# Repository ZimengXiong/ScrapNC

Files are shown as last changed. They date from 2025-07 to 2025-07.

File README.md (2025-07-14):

# ScrapNC

Low Cost, 3D Printed, minimally performant, scalable CNC router for low demanding workloads like plastics, wood, cardboard, and plotting made from common 3D Printer components; specifically upcycled from the [VzBot-330](https://github.com/VzBoT3D/VzBoT-Vz330) and the [Ender-3](https://github.com/Creality3DPrinting/Ender-3).

View the 3D Model [here](https://cad.onshape.com/documents/cc222f90ad821ffcf8e9cb61/w/239149645e138bc8923f3c63/e/6d84ac4b2727319282d79423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) in the browser.

GCode Generated with [Carbide Create](https://carbide3d.com/carbidecreate/), with custom [post-processor](CarbideCreatePostProcessor/scrapnc.post)

Runs standard [Klipper](https://github.com/Klipper3d/klipper) with [custom config](KlipperConfig)

View the models here: https://www.printables.com/model/1347866-scrapnc-low-cost-cnc-router-from-3d-printer-compon/files
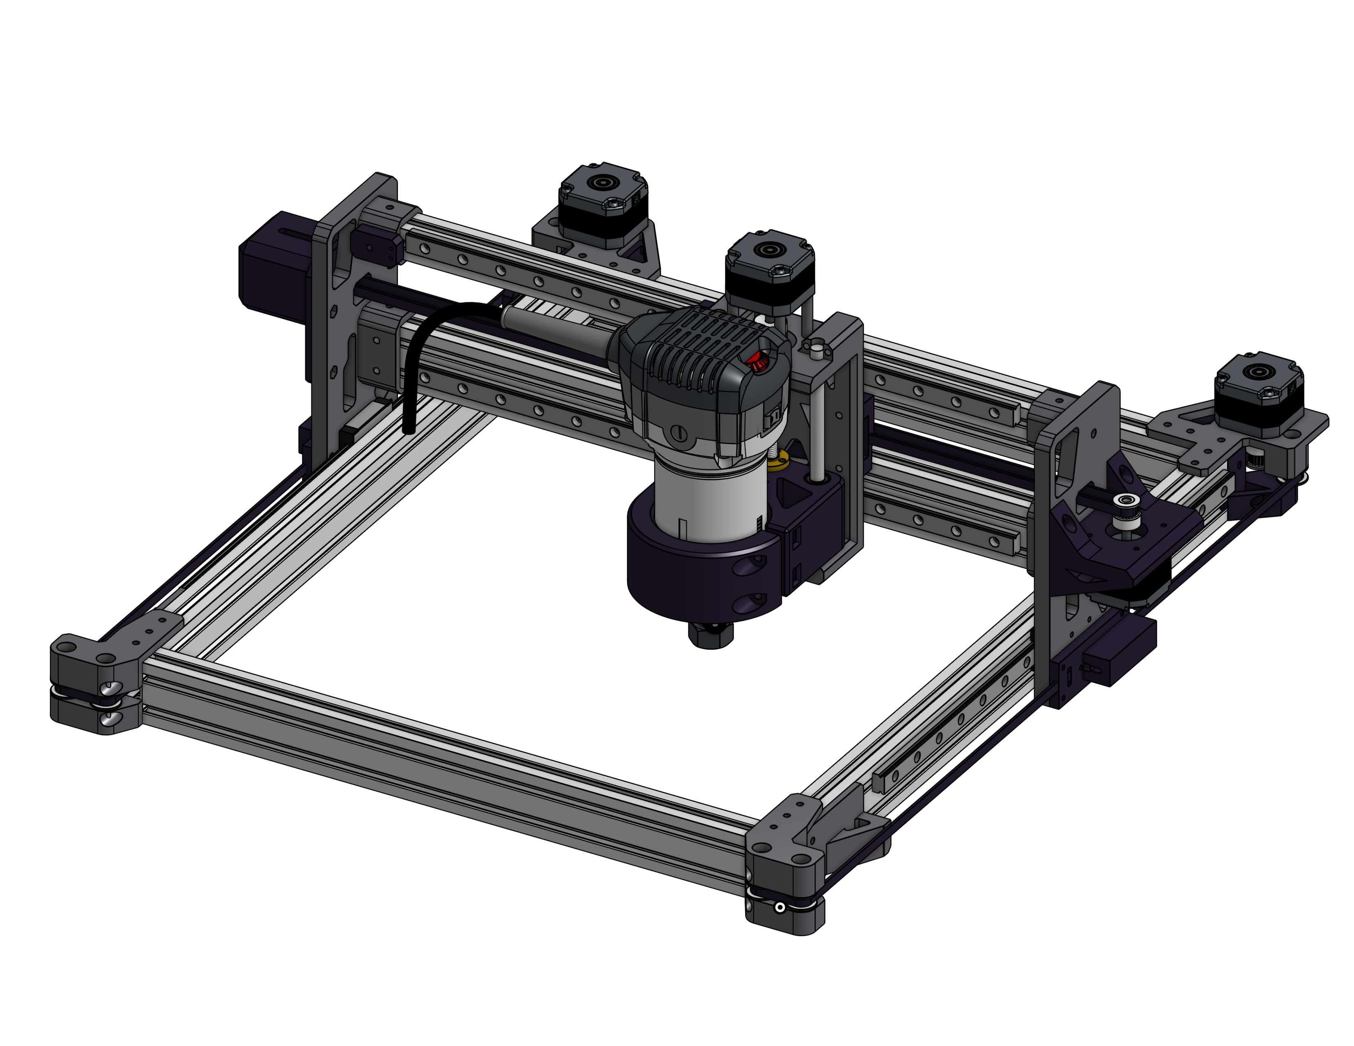
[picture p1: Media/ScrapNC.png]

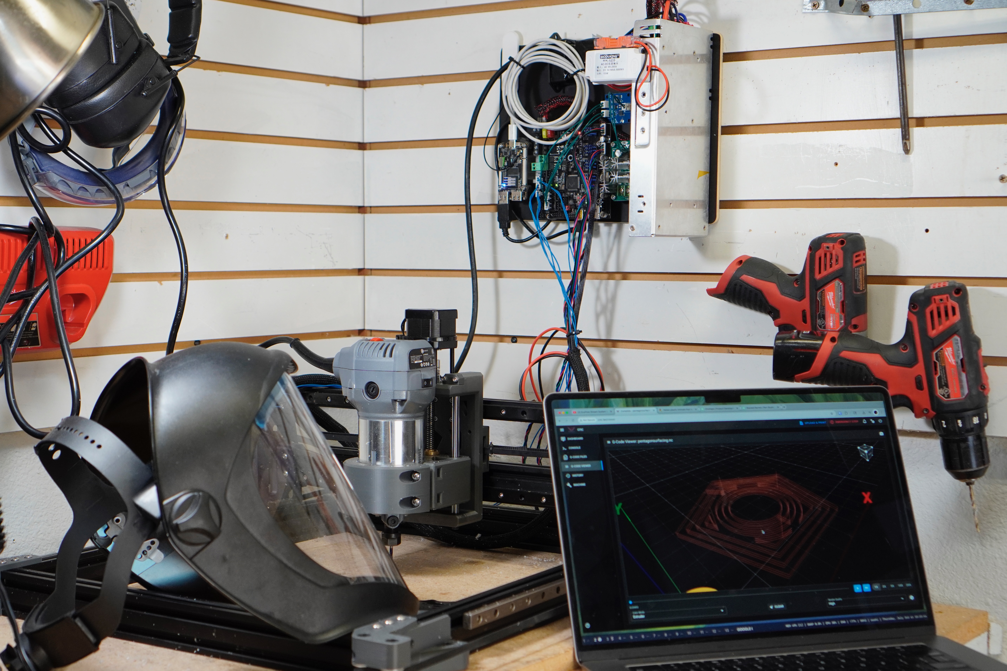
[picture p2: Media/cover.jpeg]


# Videos

## Polycarbonate

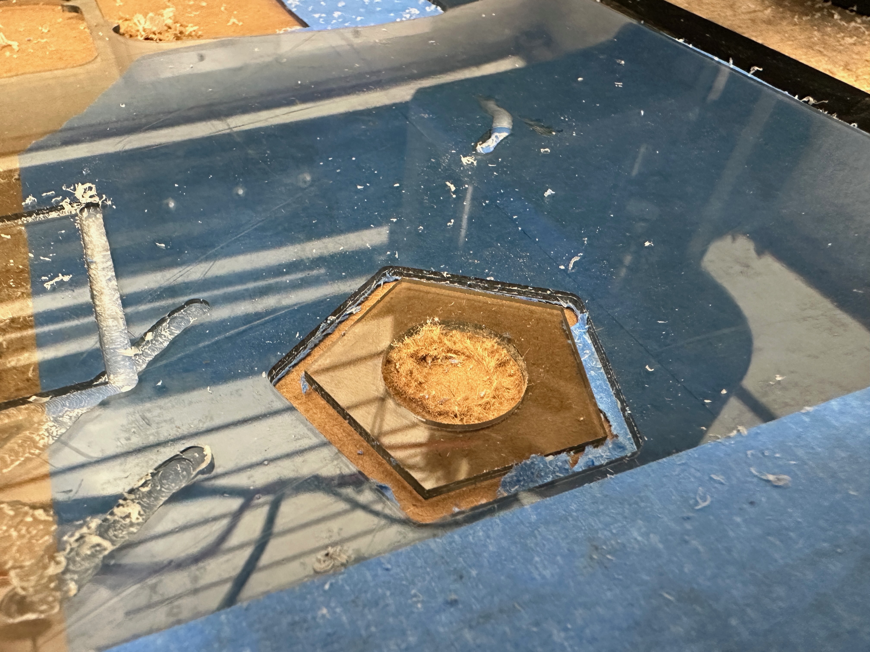
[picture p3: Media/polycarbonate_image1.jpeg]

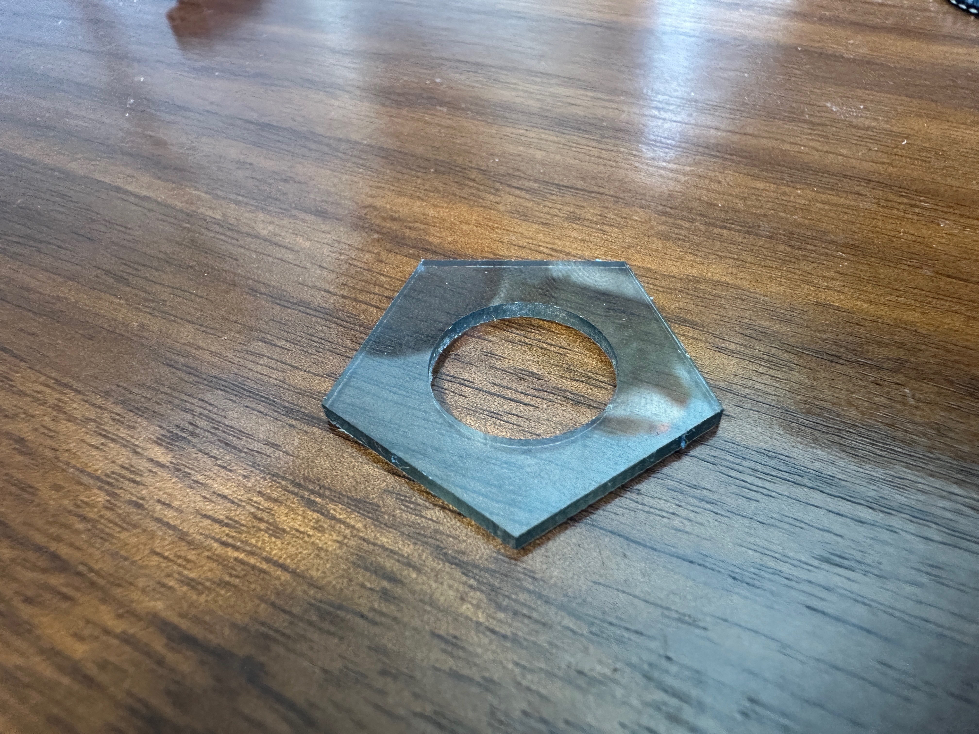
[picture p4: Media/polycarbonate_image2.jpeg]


https://github.com/user-attachments/assets/6acb7927-33cb-447a-ad85-6f1f9b60a763

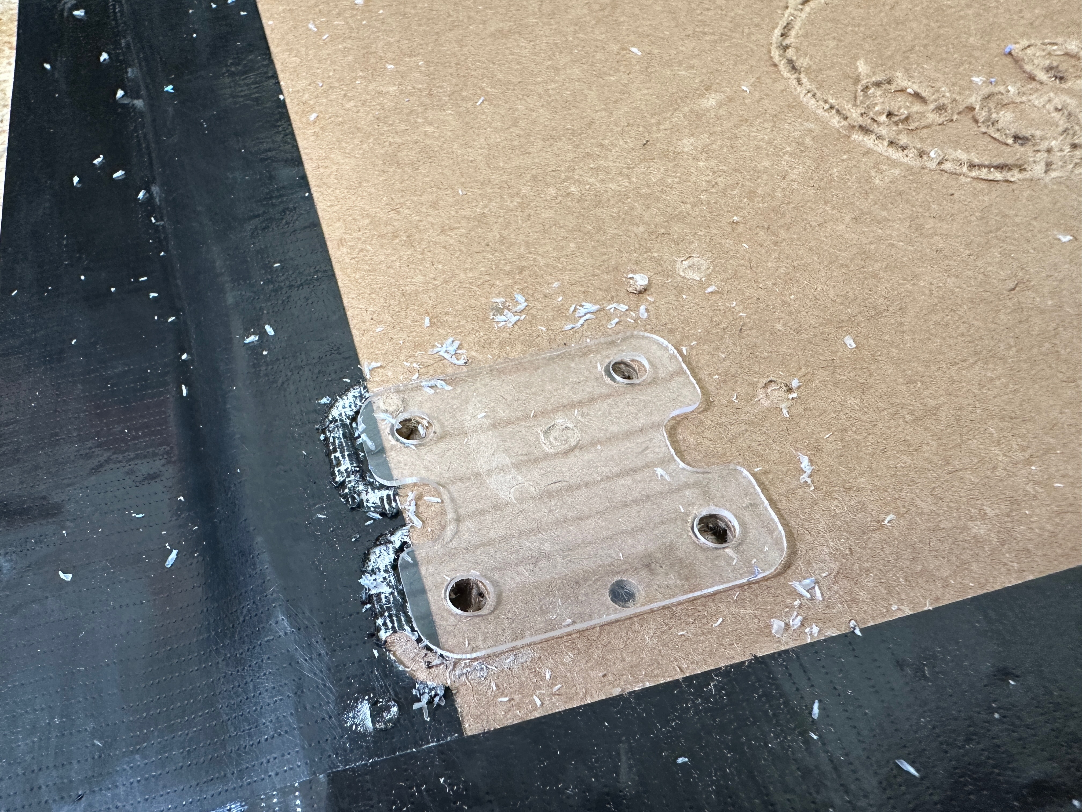
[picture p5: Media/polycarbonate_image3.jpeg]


https://github.com/user-attachments/assets/8f0fa02e-e79f-4632-babf-1fa1cd60a0c3

## Plywood

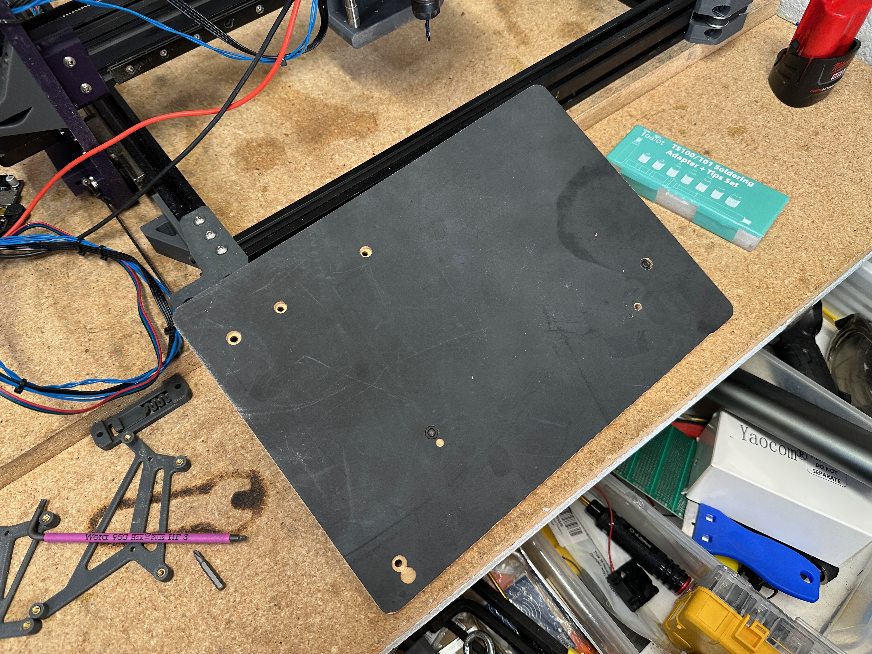
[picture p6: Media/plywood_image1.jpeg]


https://github.com/user-attachments/assets/6a91daa9-58b5-4f33-bc3b-5fa999200487

(Fail—Did not properly fasten bit)

https://github.com/user-attachments/assets/d1fd9dd1-560f-435f-840f-3c51d6c63a27

## Cardboard



https://github.com/user-attachments/assets/0a070702-a36b-4b73-86e6-df643ceed8f8



https://github.com/user-attachments/assets/c7c148f7-fc61-4ff0-bef7-0c005a5ad410

# BOM

You should have a stockpile of various screws and misc components, BOM is a constant WIP.

https://docs.google.com/spreadsheets/d/1-7GyJF8yEe2CKIwr3BQy1hE-u1tUgOVvXOGRfo0h9CQ/edit?usp=sharing

# Electronics



# Issues/Questions

For any questions, please open an Github Issue.

# More Images

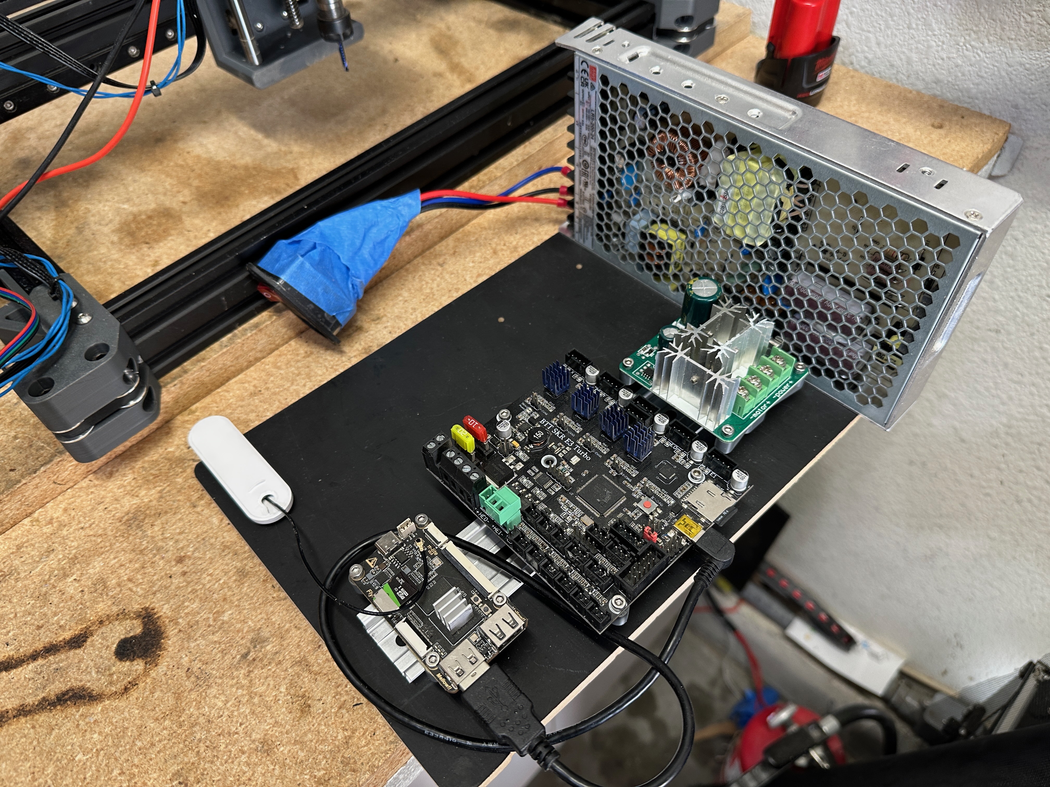
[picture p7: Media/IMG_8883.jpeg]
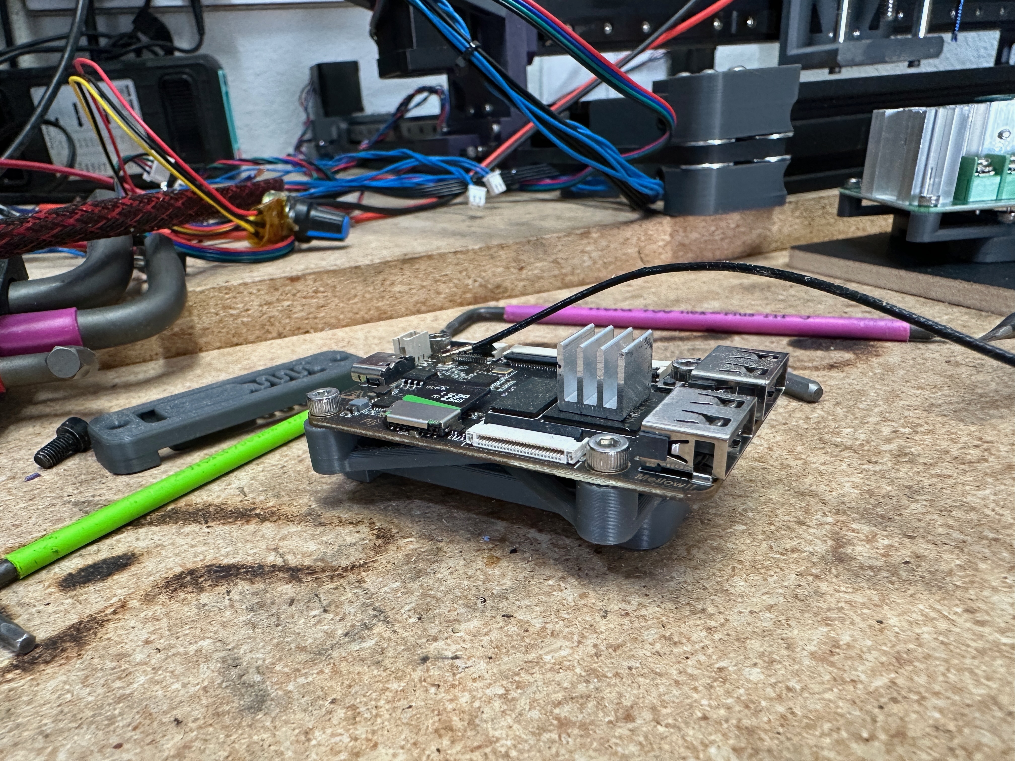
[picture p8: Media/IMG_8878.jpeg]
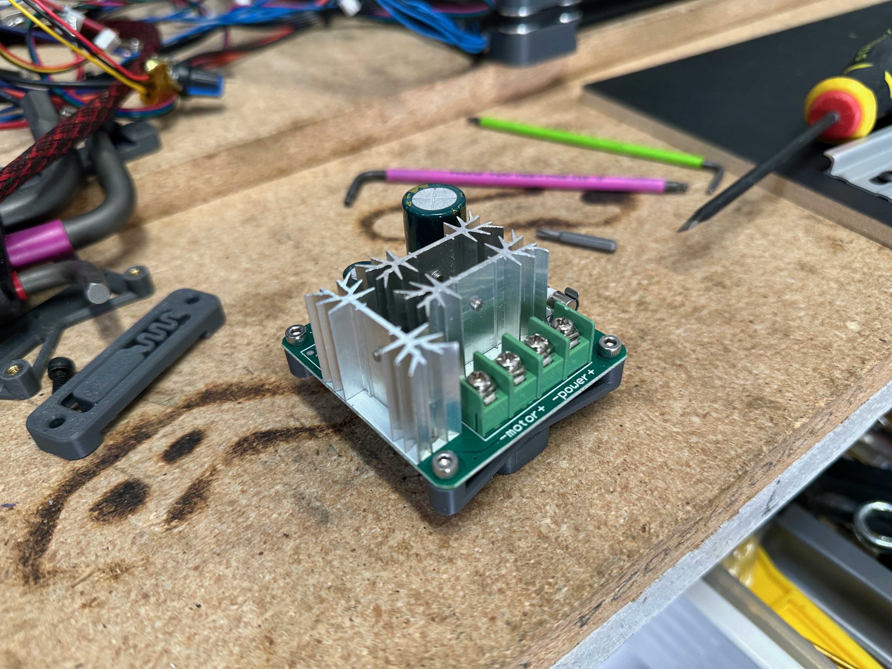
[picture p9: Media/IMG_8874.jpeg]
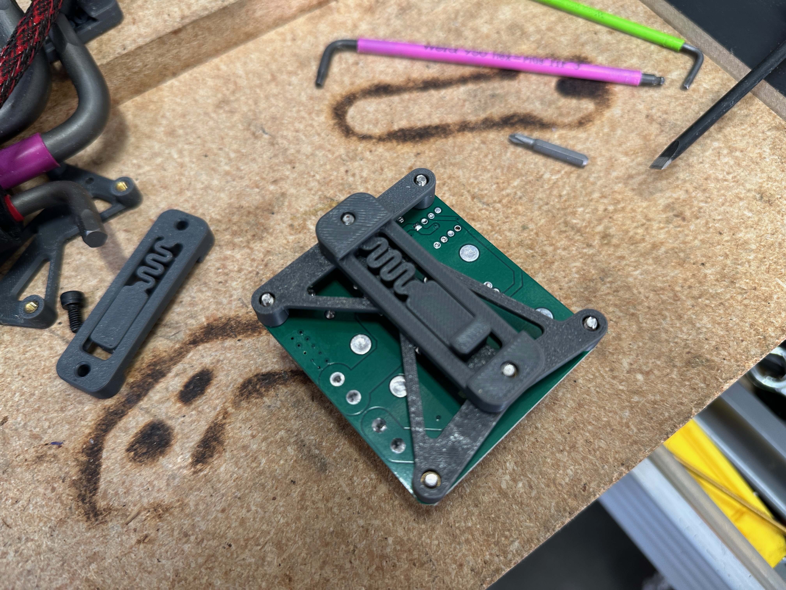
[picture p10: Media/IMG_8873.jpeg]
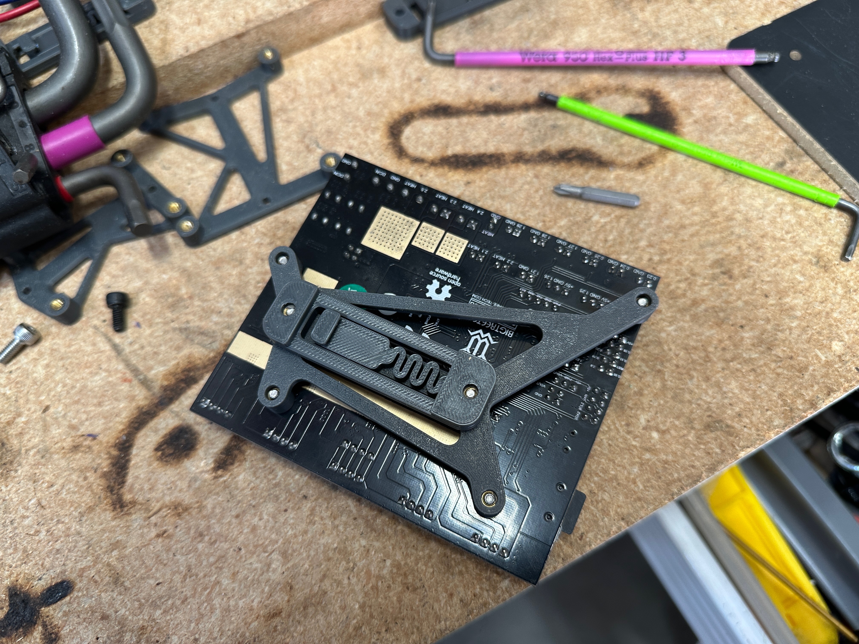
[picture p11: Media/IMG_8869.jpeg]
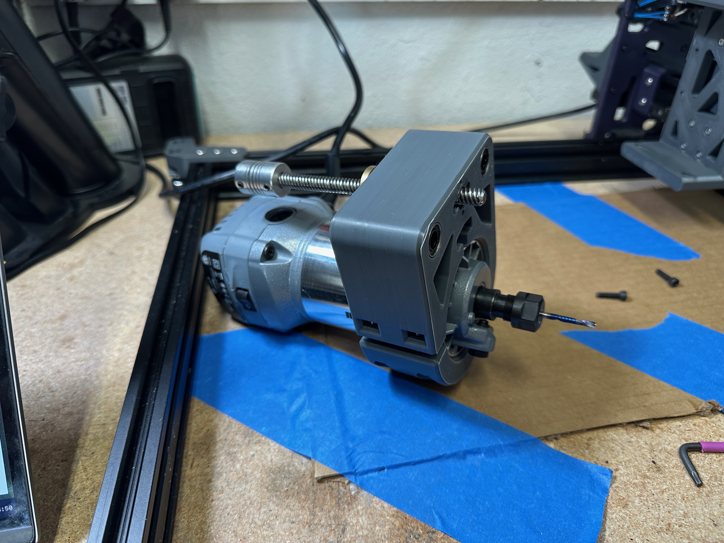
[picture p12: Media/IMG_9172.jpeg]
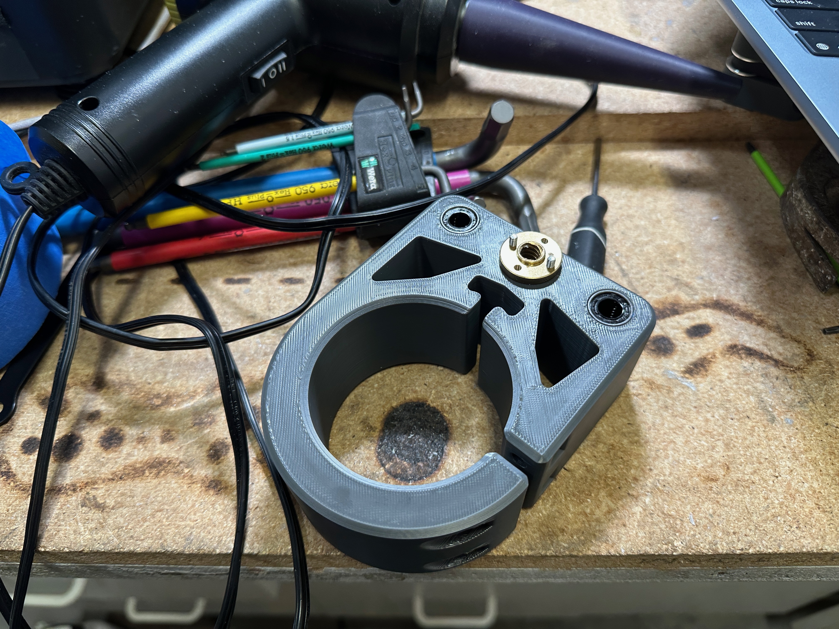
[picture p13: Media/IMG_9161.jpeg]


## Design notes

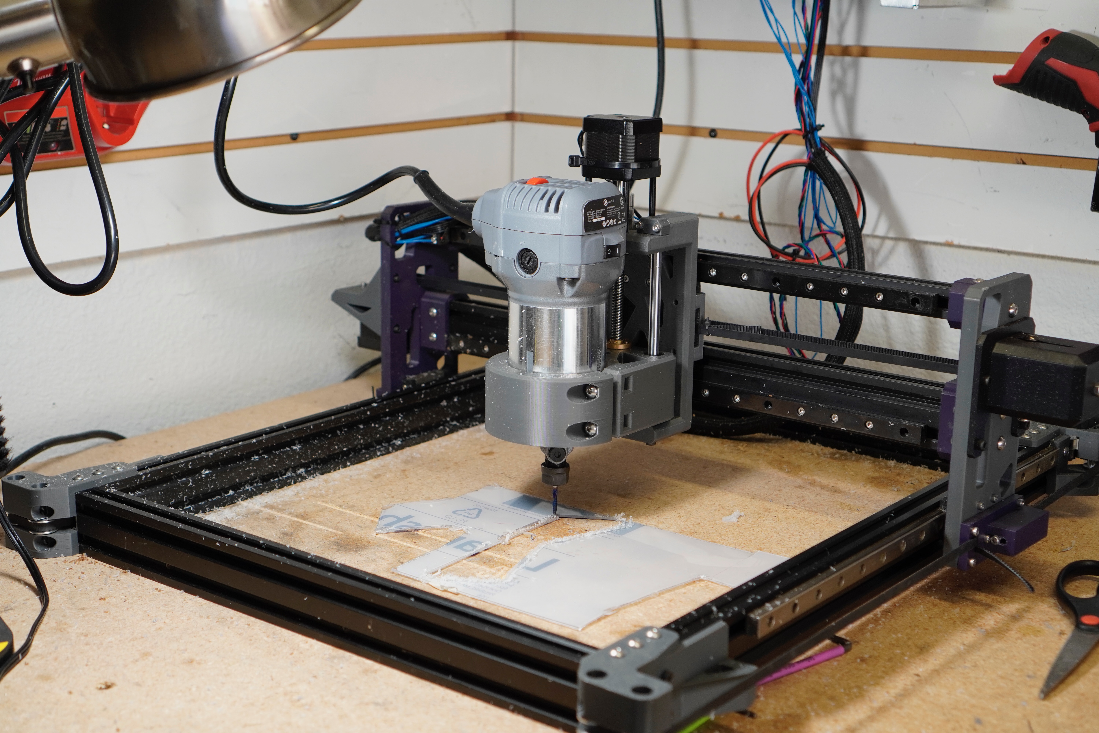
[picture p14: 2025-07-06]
Media/_DSC4514.jpeg

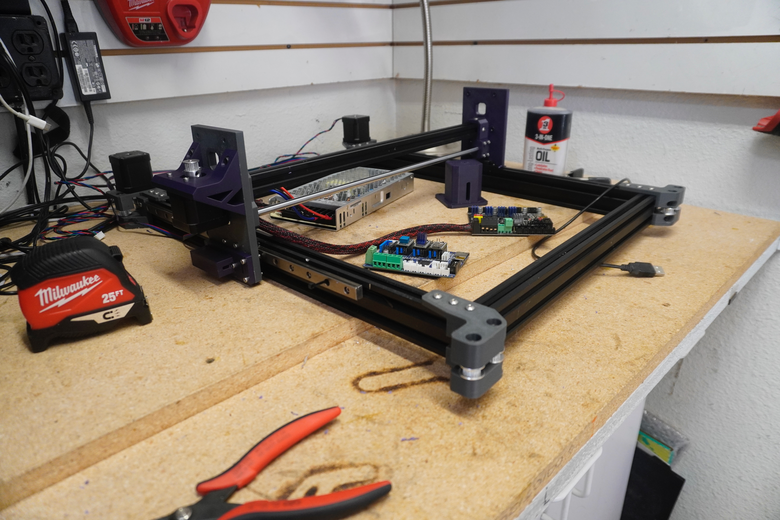
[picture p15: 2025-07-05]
Media/_DSC4143.jpeg

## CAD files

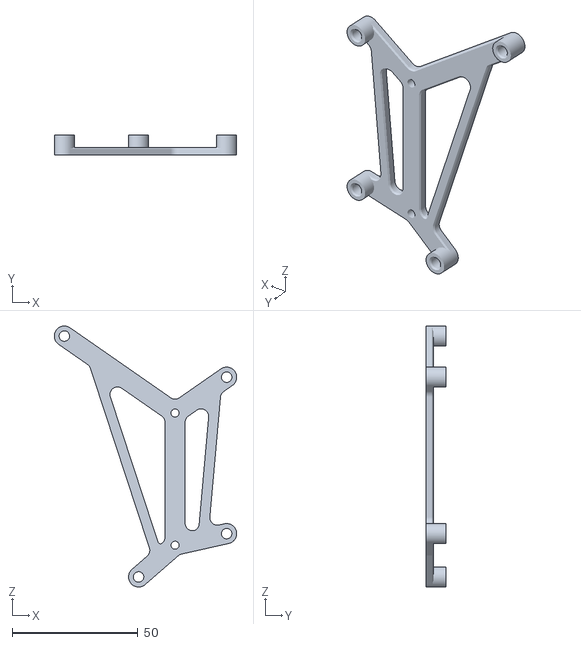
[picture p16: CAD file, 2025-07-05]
STLs/Electronics/SKR E3 Turbo_DIN.stl
72.5 x 8.00 x 103.7

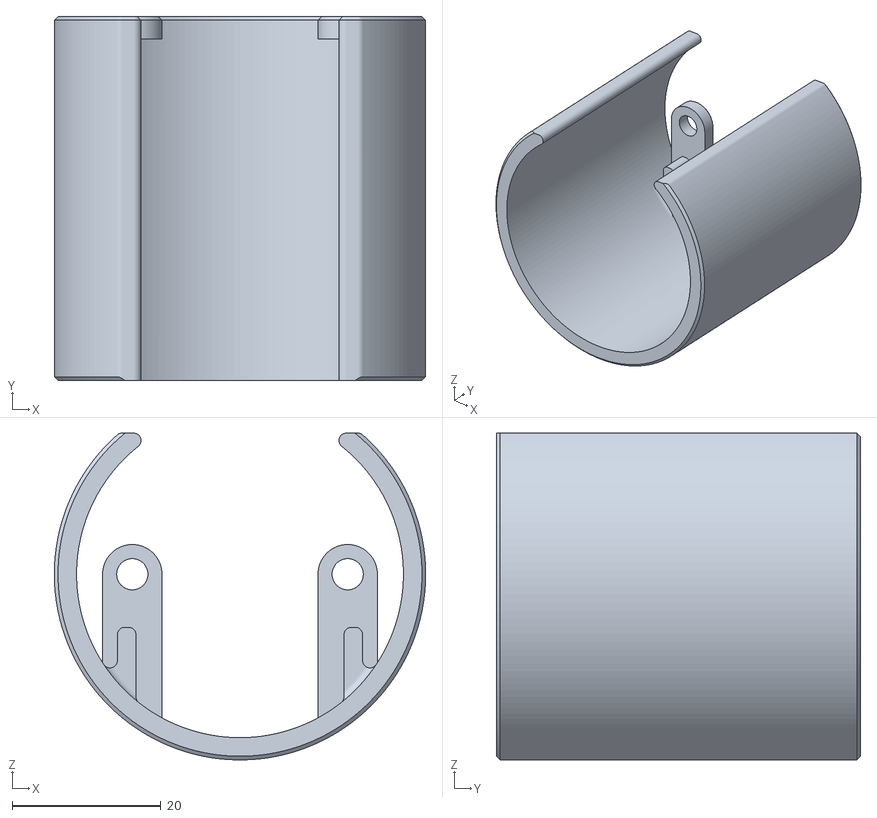
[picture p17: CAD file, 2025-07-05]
STLs/Misc/Dust Shoe.stl
50.0 x 49.0 x 44.0

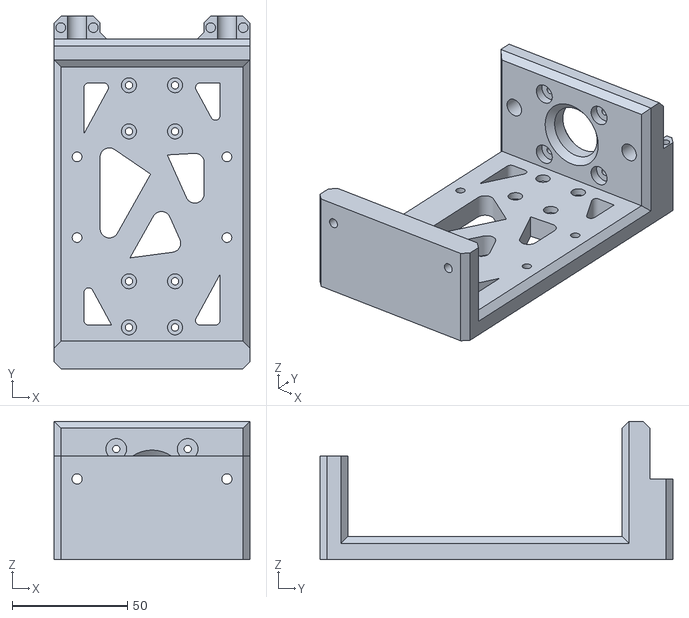
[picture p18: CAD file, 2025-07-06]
STLs/X Gantry/X Plate.stl
85.0 x 153.0 x 60.0

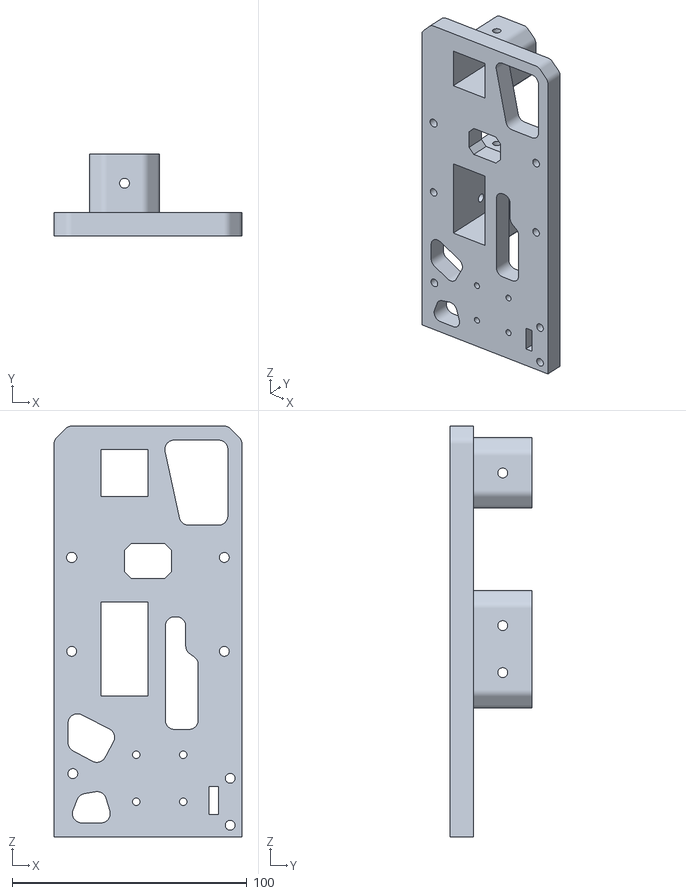
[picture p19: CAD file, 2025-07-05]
STLs/Y Axis Plate/Y Axis Plate-Mirrored.stl
80.0 x 35.0 x 175.0

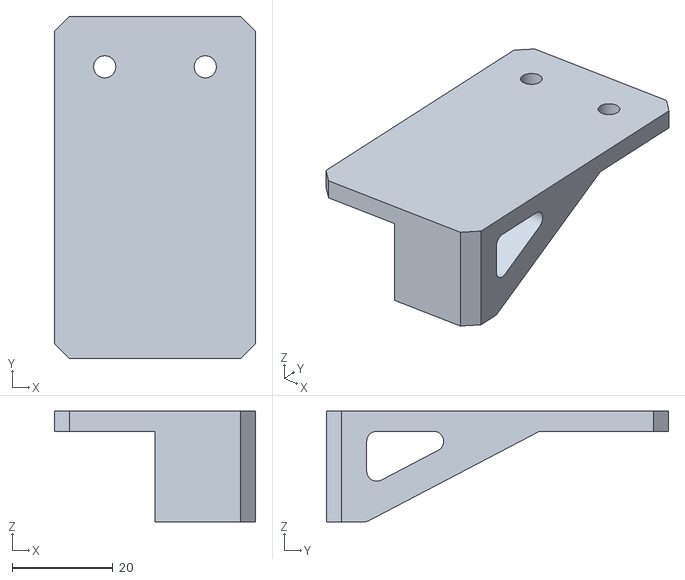
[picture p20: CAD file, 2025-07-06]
STLs/Y Axis/Y Aligner-Mirrored.stl
40.0 x 68.0 x 22.0

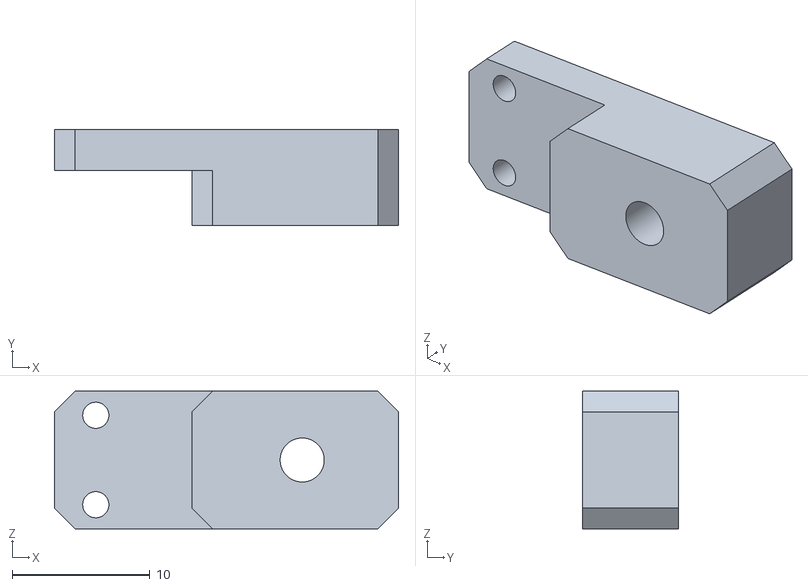
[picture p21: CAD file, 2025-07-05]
STLs/Z Assembly/Z Axis Endstop Mount.stl
25.0 x 7.00 x 10.0

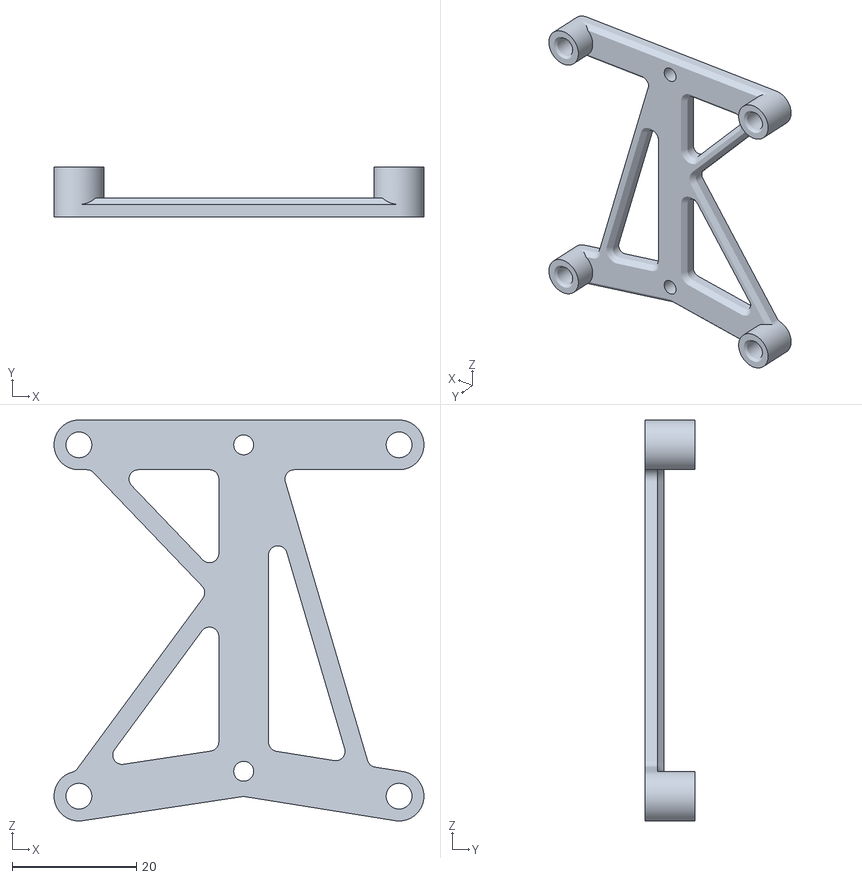
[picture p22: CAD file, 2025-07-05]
STLs/Electronics/PWM Speed Controller_DIN.stl
59.5 x 8.00 x 64.5

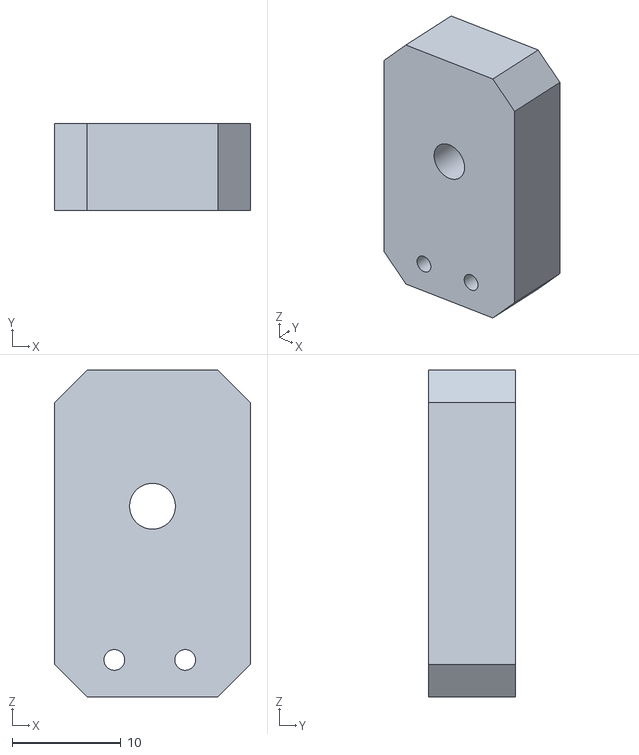
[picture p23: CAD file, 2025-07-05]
STLs/X Gantry/X Axis Endstop Mount.stl
18.0 x 8.00 x 30.0

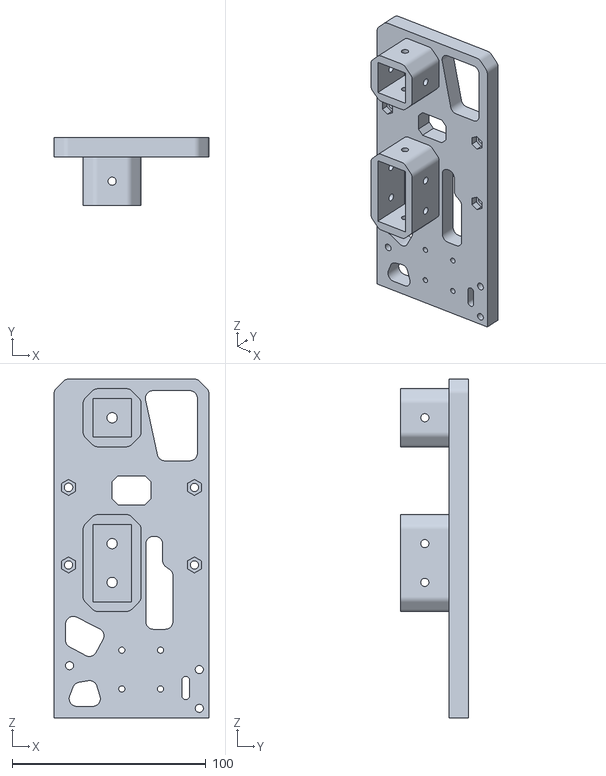
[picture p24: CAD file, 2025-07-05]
STLs/Y Axis Plate/Y Axis Plate.stl
80.0 x 35.0 x 175.0

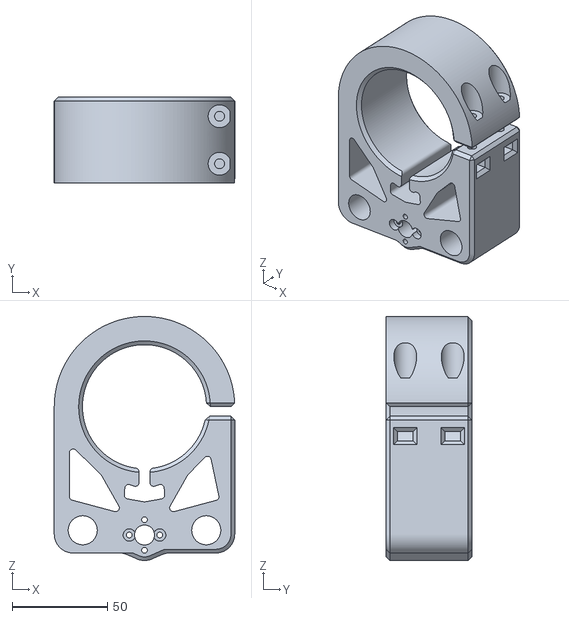
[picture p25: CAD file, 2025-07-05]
STLs/Z Assembly/Z Axis Spindle Holder.stl
95.0 x 45.0 x 128.4

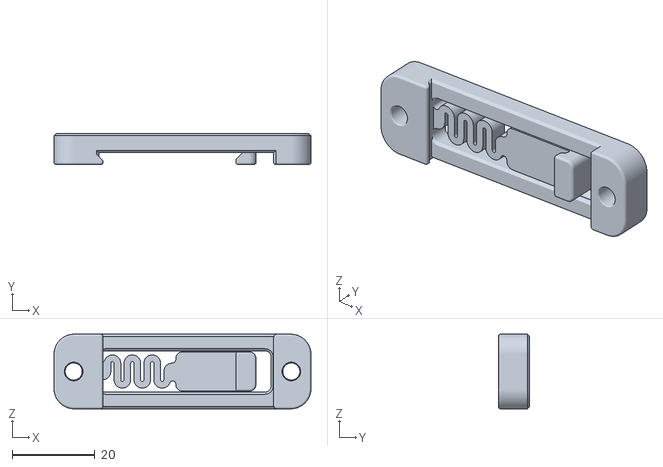
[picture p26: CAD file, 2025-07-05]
STLs/Electronics/DIN Rail Bracket Heat Insert Version.stl
62.0 x 7.50 x 18.0

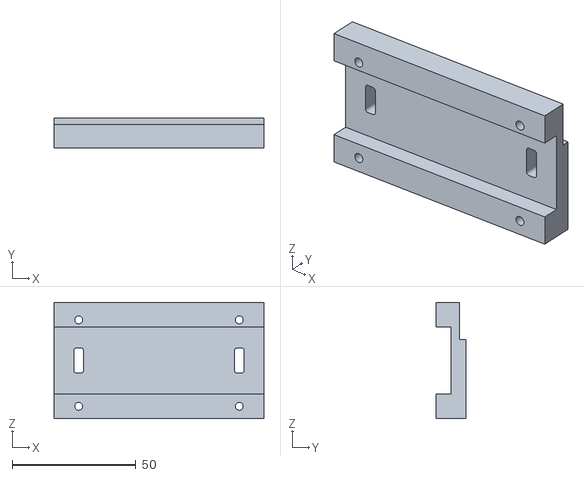
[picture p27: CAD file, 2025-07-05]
STLs/X Gantry/X Plate Belt Grabbers.stl
85.0 x 12.0 x 47.1

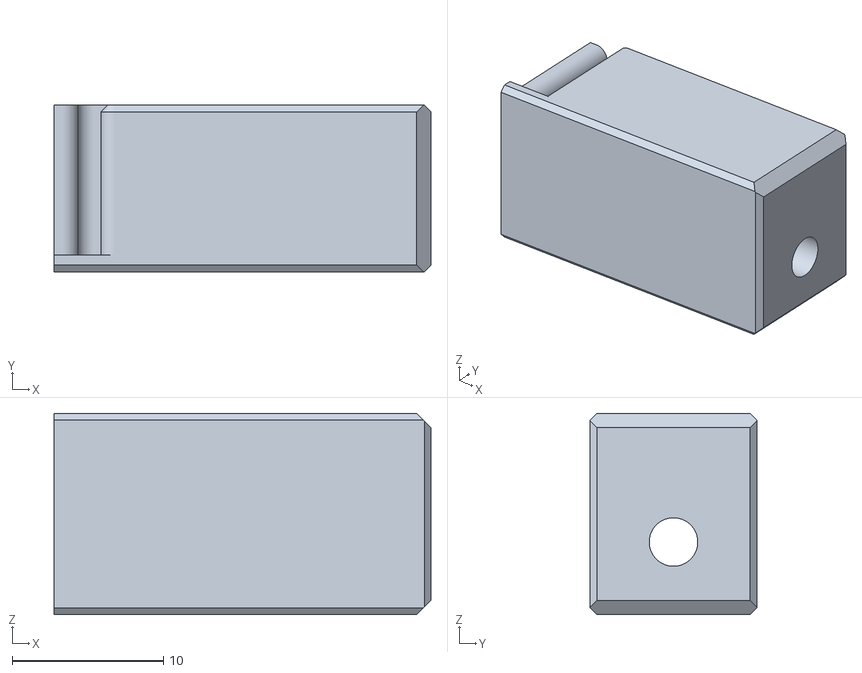
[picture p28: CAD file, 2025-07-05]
STLs/Y Axis Plate/M3 Belt Grabber.stl
24.9 x 11.0 x 13.3

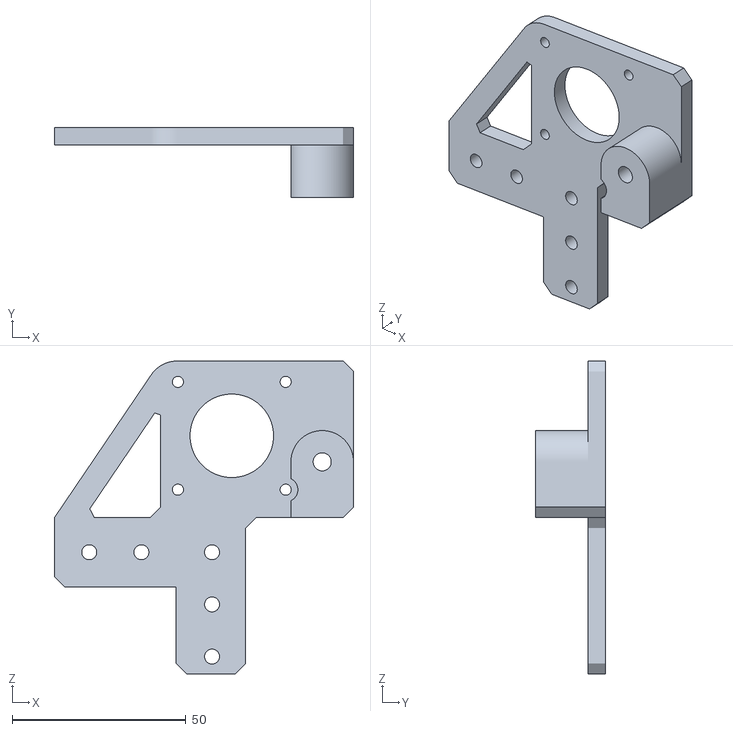
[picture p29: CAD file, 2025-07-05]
STLs/Y Axis/Y Axis Motor Mounts.stl
86.0 x 20.0 x 90.0

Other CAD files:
STLs/Y Axis/Y Aligner.stl
STLs/Z Assembly/M3 Spacer.stl
STLs/Electronics/Fly Pi Lite v2_DIN.stl
STLs/Y Axis Plate/Y Axis Plate Motor Mount.stl
STLs/Y Axis Plate/Y Axis Belt Tensioner Module.stl
STLs/Y Axis Plate/Y Axis Plate Idler Tensioner Mount.stl
STLs/Y Axis/Back Idler Mount Bottom.stl
STLs/Y Axis/Back Idler Mount Top.stl
STLs/Y Axis/Y Axis Endstop Mount.stl
STLs/Y Axis/Y Axis Front Idler Mount.stl
STLs/Y Axis/Y Axis Motor Mount Support.stl

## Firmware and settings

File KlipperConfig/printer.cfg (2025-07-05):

[include mainsail.cfg]
[include cnc.cfg]
[gcode_arcs]

[force_move]
enable_force_move: True

[stepper_x]
step_pin: P1.4
dir_pin: P1.8
enable_pin: !P1.0
microsteps: 16
rotation_distance: 40
endstop_pin: ^!P1.29
position_endstop: 0
position_max: 320
homing_speed: 50

[tmc2209 stepper_x]
uart_pin: P1.1
#diag_pin: P1.29
run_current: 0.8
stealthchop_threshold: 0

[stepper_y]
step_pin: P1.14
dir_pin: !P1.15
enable_pin: !P1.9
microsteps: 16
rotation_distance: 40
endstop_pin: ^!P1.28
position_endstop: 320
position_max: 320
homing_speed: 50

[tmc2209 stepper_y]
uart_pin: P1.10
#diag_pin: P1.28
run_current: 0.5
stealthchop_threshold: 0

[stepper_y1]
step_pin: P2.6
dir_pin: P2.7
enable_pin: !P0.4
microsteps: 16
rotation_distance: 40

[tmc2209 stepper_y1]
uart_pin: P0.22
#diag_pin: P1.25
run_current: 0.8
stealthchop_threshold: 0


[stepper_z]
step_pin: P4.29
dir_pin: !P4.28
enable_pin: !P1.16
microsteps: 16
rotation_distance: 8
endstop_pin: ^!P1.27
position_endstop: 60
position_min: 0
position_max: 60

[tmc2209 stepper_z]
uart_pin: P1.17
#diag_pin: P1.27
run_current: 0.8
stealthchop_threshold: 0


# [tmc2209 extruder]
# uart_pin: P0.5
# #diag_pin: P1.26
# run_current: 0.650
# stealthchop_threshold: 999999

#[extruder1]
#step_pin: P2.11
#dir_pin: P2.12
#enable_pin: !P0.21
#heater_pin: P2.4
#sensor_pin: P0.23
#...

[fan_generic spindle]
pin: P1.25
max_power: 1

# [fan]
# pin: P2.1

# [heater_fan heatbreak_cooling_fan]
# pin: P2.2

[mcu]
serial: /dev/serial/by-id/usb-Klipper_lpc1769_15200004A49869AF87DA3E5EC52000F5-if00

[printer]
kinematics: cartesian
max_velocity: 100
max_accel: 300
max_z_velocity: 5
max_z_accel: 100

[static_digital_output tmc_standby_pins]
pins: !P3.26, !P3.25, !P1.18, !P1.19, !P2.13

[board_pins]
aliases:
    # EXP1 header
    EXP1_1=P2.8,  EXP1_3=P0.19, EXP1_5=P0.20, EXP1_7=P0.17, EXP1_9=<GND>,
    EXP1_2=P0.16, EXP1_4=<RST>, EXP1_6=P0.15, EXP1_8=P0.18, EXP1_10=<5V>


[display]
lcd_type: st7920
cs_pin: EXP1_7
sclk_pin: EXP1_6
sid_pin: EXP1_8
encoder_pins: ^EXP1_5, ^EXP1_3
click_pin: ^!EXP1_2

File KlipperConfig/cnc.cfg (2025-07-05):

[gcode_macro G00]
gcode:  
    G1 {% for p in params %}{'%s%s' % (p, params[p])}{% endfor %}
    
[gcode_macro G01]
gcode: 
    G1 {% for p in params %}{'%s%s' % (p, params[p])}{% endfor %}

[gcode_macro G02]
gcode: 
    G2 {% for p in params %}{'%s%s' % (p, params[p])}{% endfor %}

[gcode_macro G03]
gcode: 
    G2 {% for p in params %}{'%s%s' % (p, params[p])}{% endfor %}

[gcode_macro G04]
gcode: 
    G4 {% for p in params %}{'%s%s' % (p, params[p])}{% endfor %}

# M3
# Spindle direction clockwise (starts the spindle)
[gcode_macro M03]
gcode:
    {% set S = params.S|default(1000)|int %}
    SET_FAN_SPEED FAN=spindle SPEED={S/20000.0}

# M5
# Stop Spindle Rotation
[gcode_macro M05]
gcode:
    SET_FAN_SPEED FAN=spindle SPEED=0

# M2
# Program Pause and End
[gcode_macro M02]
gcode:

[gcode_macro SET_Z_ZERO]
gcode:
  SET_KINEMATIC_POSITION Z=0

[gcode_macro SET_Z_25]
gcode:
  SET_KINEMATIC_POSITION Z=25

[gcode_macro SET_Z_50]
gcode:
  SET_KINEMATIC_POSITION Z=50
  
[gcode_macro SET_XY_ZERO]
gcode:
  SET_KINEMATIC_POSITION X=0 Y=0

[gcode_macro SET_ZERO]
gcode:
  SET_KINEMATIC_POSITION X=0 Y=0 Z=0

[gcode_macro PAUSE]
variable_paused_z: 0
rename_existing: PAUSE_BASE
gcode:
  # Save the current G-code state
  SAVE_GCODE_STATE NAME=PAUSE_state

  M5 # Stop the spindle

  PAUSE_BASE

[gcode_macro RESUME]
rename_existing: RESUME_BASE
gcode:
  {% set svv = printer.save_variables.variables %}
  M3 S{svv.spindle_speed} 
  
  # Restore the previously saved G-code state
  RESTORE_GCODE_STATE NAME=PAUSE_state MOVE=0

  RESUME_BASE

[gcode_macro CANCEL_PRINT]
rename_existing: CANCEL_PRINT_BASE
gcode:
  M5  # Stop the spindle
  M84 X Y Z # Turn off the motors
  CANCEL_PRINT_BASE

# G28: Custom homing sequence
[gcode_macro G28]
rename_existing: G28.0
gcode:
  # Define default behavior when no specific axis is requested
  {% set home_all = 'X' not in params and 'Y' not in params and 'Z' not in params %}
  
  # Home Z first if requested or if no axes are specified to avoid collisions
  {% if 'Z' in params or home_all %}
    G28.0 Z
  {% endif %}

  # Home X and Y; home both if no specific axis is mentioned
  {% if 'X' in params or 'Y' in params or home_all %}
    G28.0 {% if 'X' in params or home_all %}X{% endif %} {% if 'Y' in params or home_all %}Y{% endif %}
  {% endif %}
  
  # Force Absolute positioning mode
  G90

[gcode_macro FLATTEN_AREA]
gcode:

    {% set start_x = params.START_X|default(0)|float %}
    {% set start_y = params.START_Y|default(0)|float %}

    {% set end_x = params.END_X|default(printer.configfile.config["stepper_x"].position_max|float)|float %}
    {% set end_y = params.END_Y|default(printer.configfile.config["stepper_y"].position_max|float)|float %}

    {% set cut_depth = params.CUT_DEPTH|default(-0.5)|float %}

    {% set feed_rate = (params.FEED_RATE|default(10)|float) * 60 %} # Convert mm/s to mm/min
    {% set step_over = params.STEP_OVER|default(15)|float %}
    {% set spindle_speed = params.SPINDLE_SPEED|default(10000)|float %}

    {% set max_z_with_offset = printer.configfile.config["stepper_z"].position_max|float - printer.gcode_move.homing_origin.z|float %}
    
    # Calculate the number of steps needed, ensuring it's an integer
    {% set num_steps = (((end_y - start_y - step_over) / step_over)|round(0, 'ceil'))|int %}

    RESPOND PREFIX="warning" MSG="Offsets are obeyed by this macro" 
    RESPOND PREFIX="info" MSG="Flattening Area: ({start_x}, {start_y}) to ({end_x}, {end_y}), cut depth: {cut_depth}" 

    G90 ; Absolute positioning
    G21 ; Set units to millimeters
    
    M3 S{spindle_speed}
    G0 Z5

    # Perimeter cut
    G0 X{start_x} Y{start_y} F{feed_rate}
    G1 Z{cut_depth} F{feed_rate / 2}
    G1 X{end_x} F{feed_rate} ; Cut along the X axis
    G1 Y{end_y} F{feed_rate} ; Cut along the Y axis
    G1 X{start_x} F{feed_rate} ; Cut back along the X axis
    G1 Y{start_y} F{feed_rate} ; Cut back along the Y axis

    #End position X=0 Y=0
    G0 X{step_over} F{feed_rate} ; Move to start position at current row

    # Sequential pattern cut
    {% for i in range(num_steps) %}
        {% set ypos = i * step_over + step_over %}
        G0 Y{ypos} F{feed_rate} ; Move to next row

        {% if i % 2 == 1 %}
          # The code here will execute if 'i' is odd.
          G0 X{step_over} F{feed_rate} ; Move to the step_over (near x_min) to perform a cut on moves 1, 3, 5 etc
        {% else %}
          G0 X{end_x - step_over} F{feed_rate} ; Move to the x_max minus step_over to perform a cut on moves 0, 2, 4 etc
        {% endif %}

    {% endfor %}

    G0 Z5 ; Raise to safety height
